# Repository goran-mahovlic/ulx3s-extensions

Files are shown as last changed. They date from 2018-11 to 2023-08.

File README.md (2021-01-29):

# Extension boards for ULX3S



    [x] RFM9X
    [x] OV7670
    [x] GPDI Input/output
    [x] MLX90640
    [x] I2S microphone
    [x] DB9
    [x] SD Card
    [x] MAX31855
    [x] ENC28J60
    [o] I2S Audio
    [o] MIDI in/out
    [o] Poteciometers
    [o] VGA
    [ ] Rotary encoder
    [ ] DC Motor with encoder
    [ ] LCD - DS90CF363B    
    [ ] CH376
    [ ] CAN bus
    [ ] LVDS
    [x] SX1257 - Already in development
    [x] RaspiCam - https://github.com/daveshah1/pmods
 
LoRa front

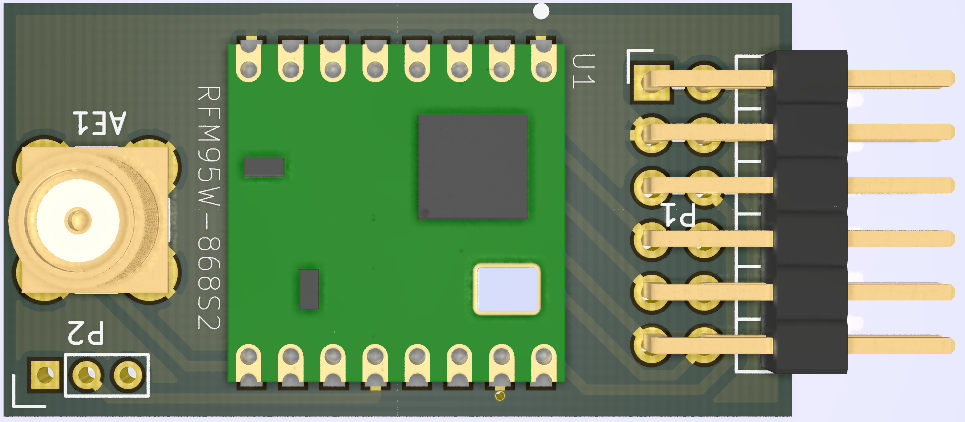
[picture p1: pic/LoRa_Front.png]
LoRa


LoRa back

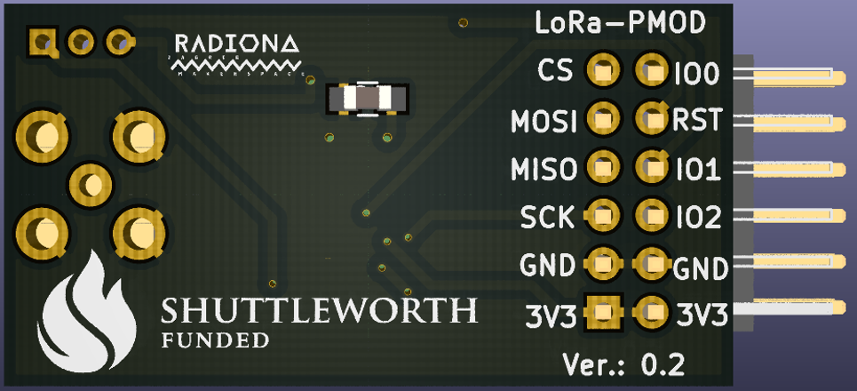
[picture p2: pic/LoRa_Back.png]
LoRa


LoRa rotate

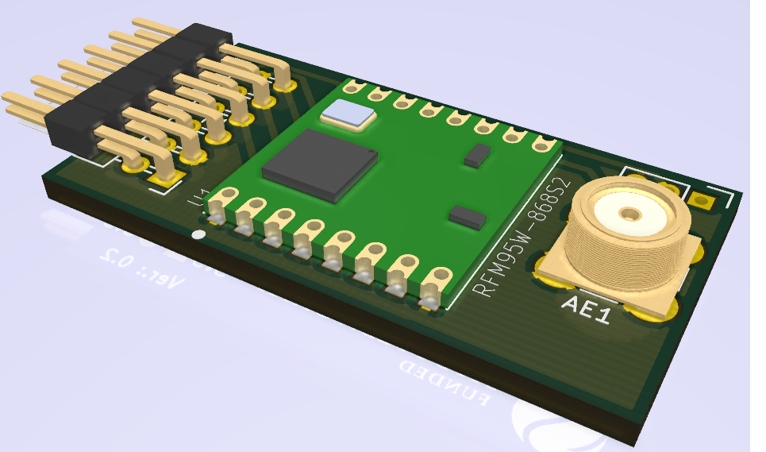
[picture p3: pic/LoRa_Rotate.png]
LoRa


MicroUSB front

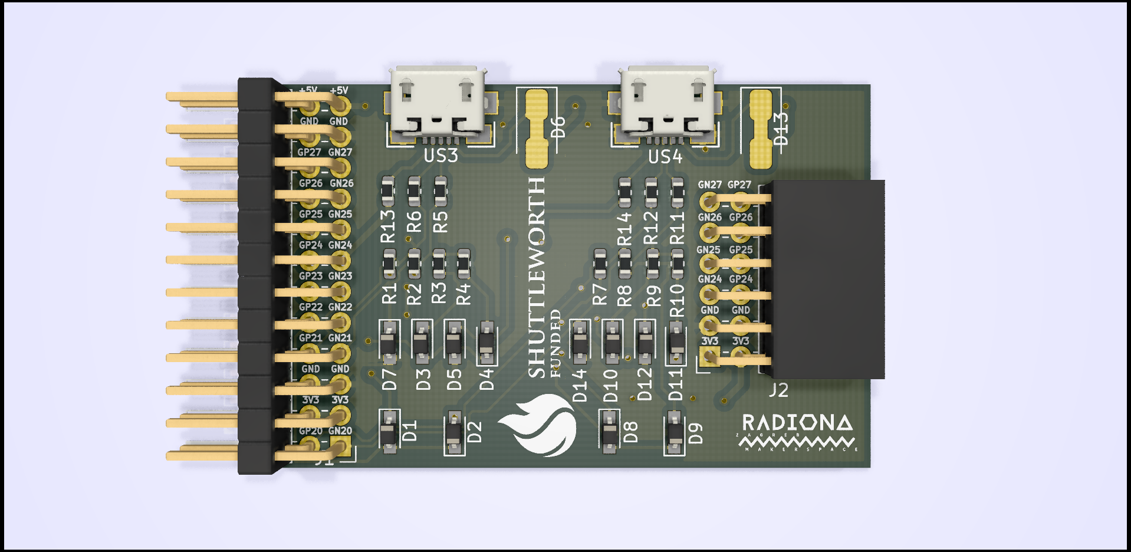
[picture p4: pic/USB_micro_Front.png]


MicroUSB back

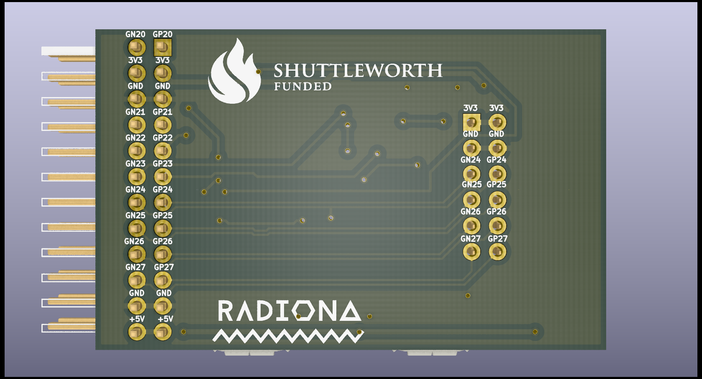
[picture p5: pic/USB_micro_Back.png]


MicroUSB rotate

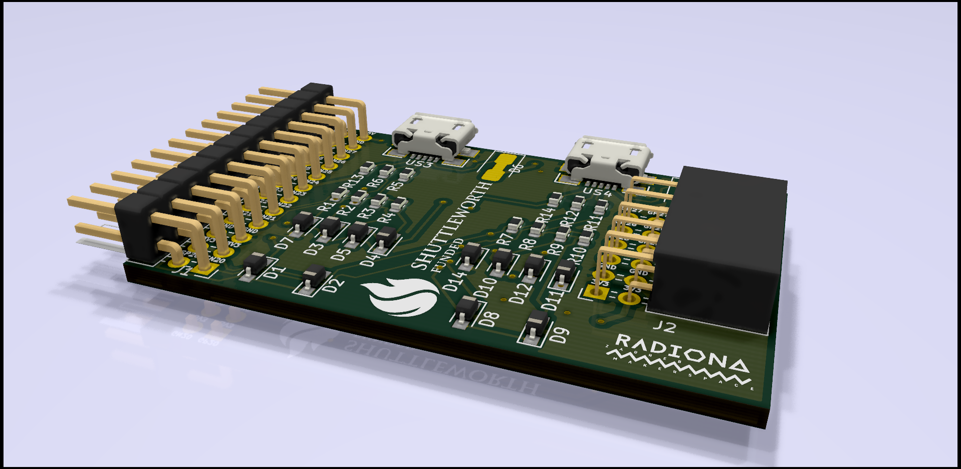
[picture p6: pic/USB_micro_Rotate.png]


USB front

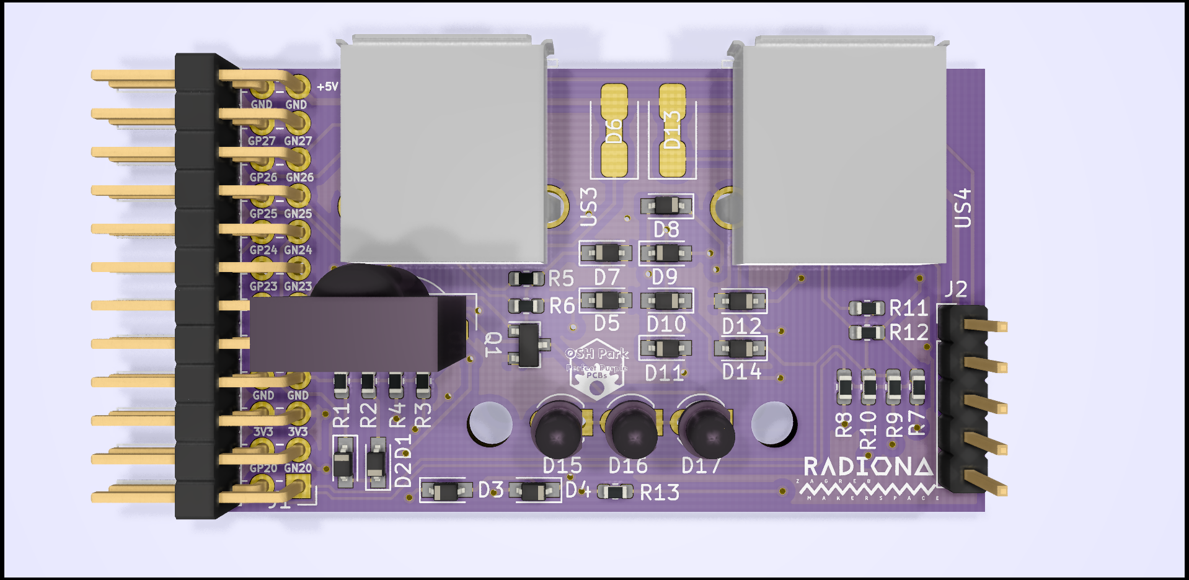
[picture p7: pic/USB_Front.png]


USB back

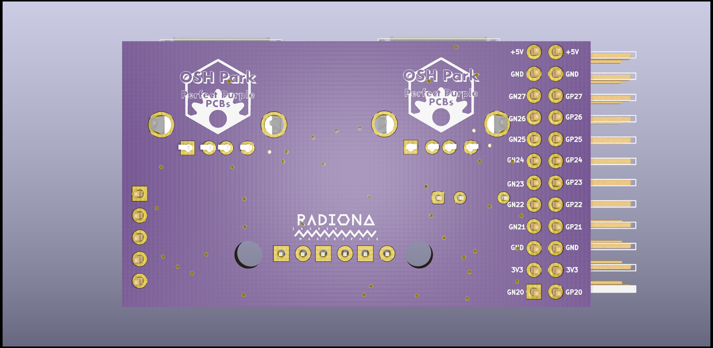
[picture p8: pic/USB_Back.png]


USB rotate

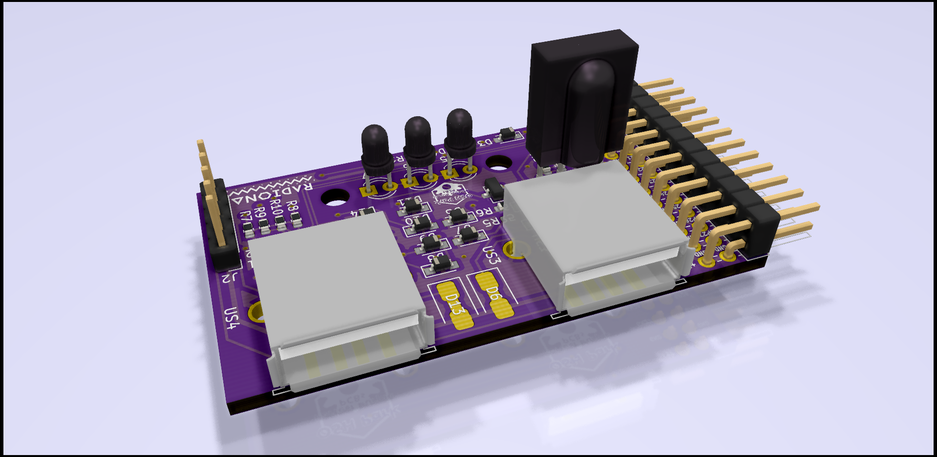
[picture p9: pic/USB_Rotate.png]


ENC28J60 front

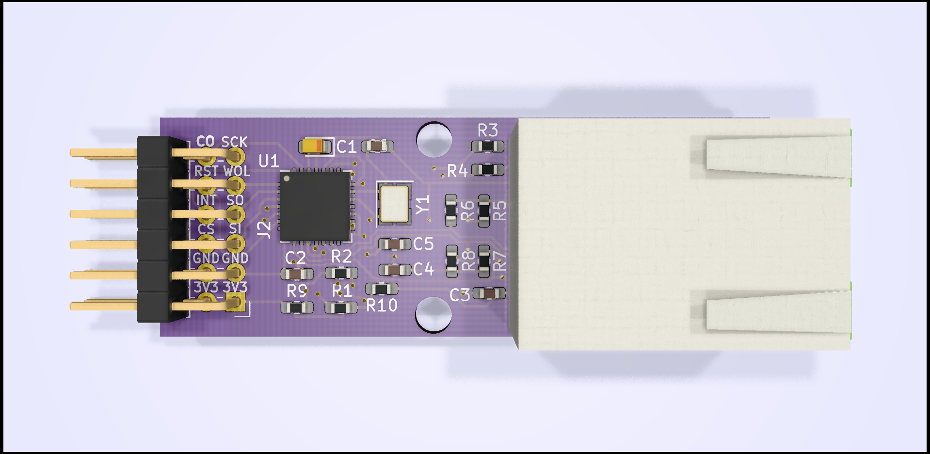
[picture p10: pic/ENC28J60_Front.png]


ENC28J60 rotate

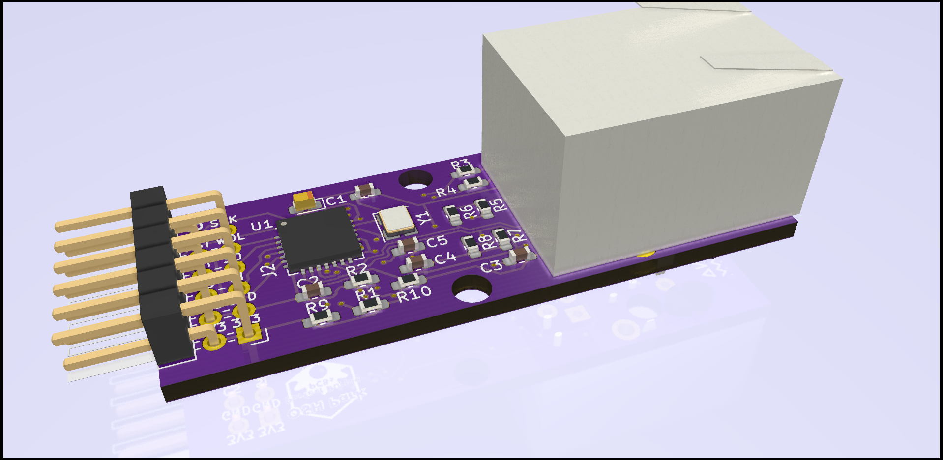
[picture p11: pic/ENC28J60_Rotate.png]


GPDI front

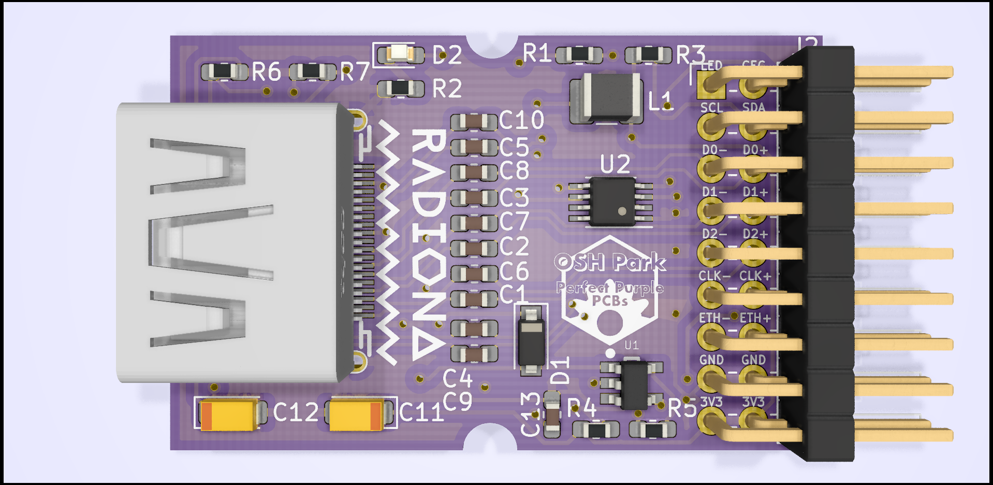
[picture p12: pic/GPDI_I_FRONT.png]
GPDI


GPDI back

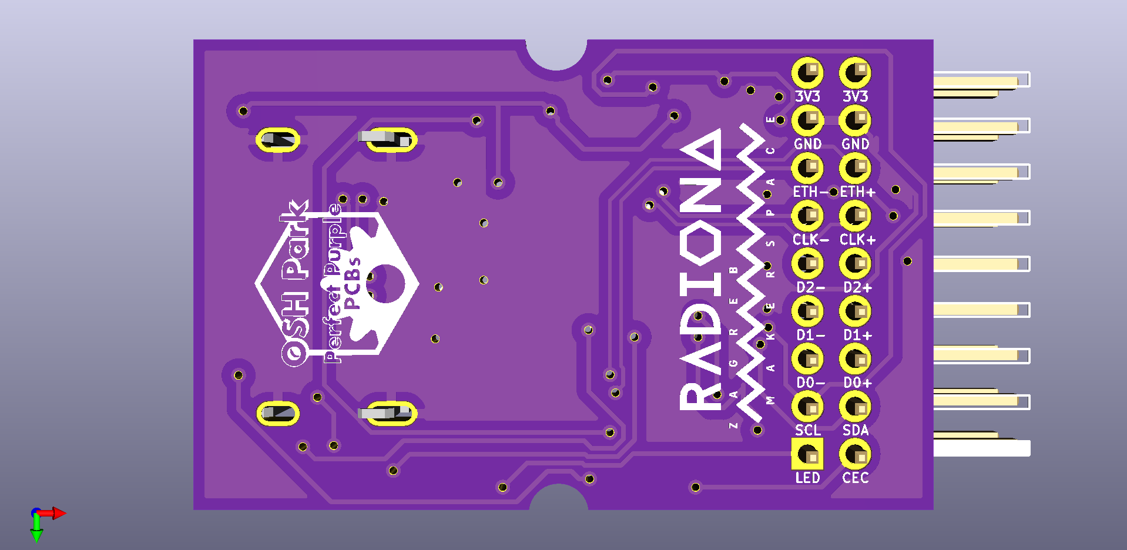
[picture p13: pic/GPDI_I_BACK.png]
GPDI


GPDI rotate

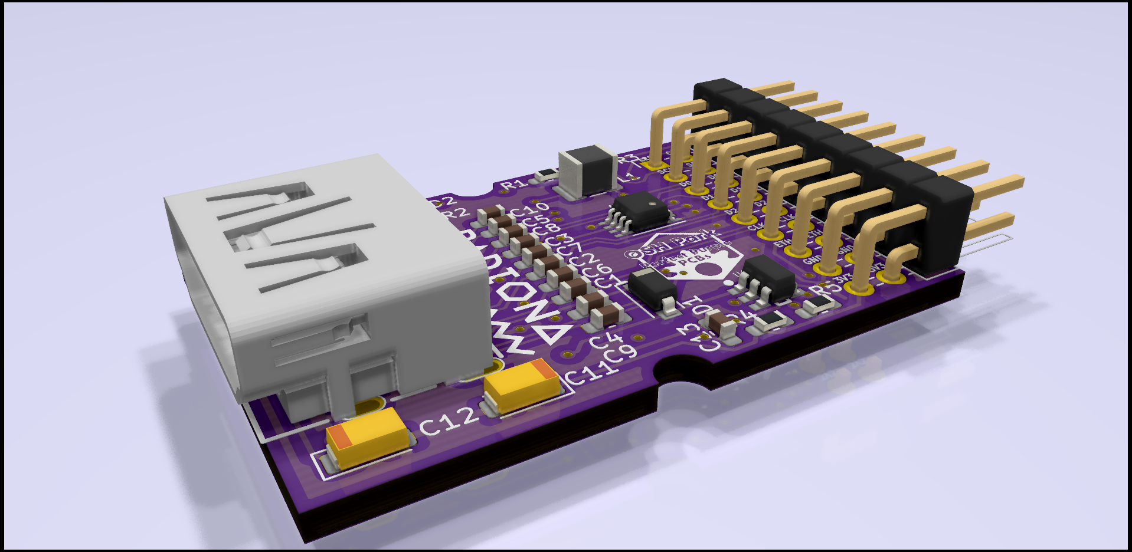
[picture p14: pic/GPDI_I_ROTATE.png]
GPDI


Potenciometar front

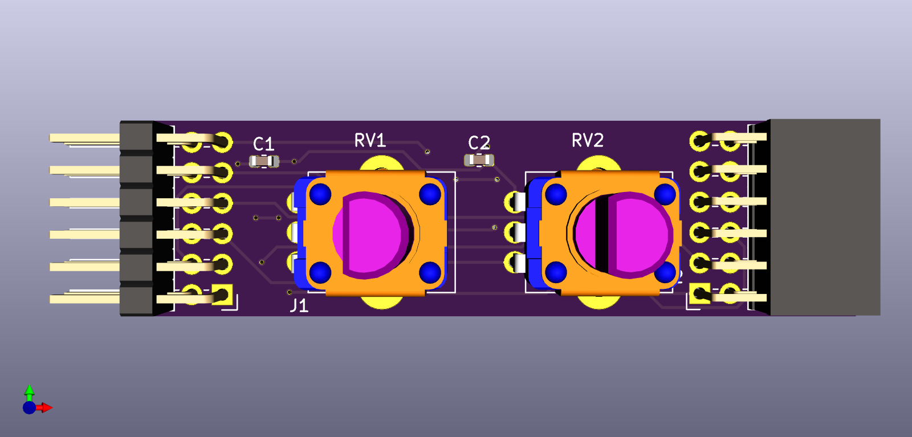
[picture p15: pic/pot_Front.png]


Potenciometar back

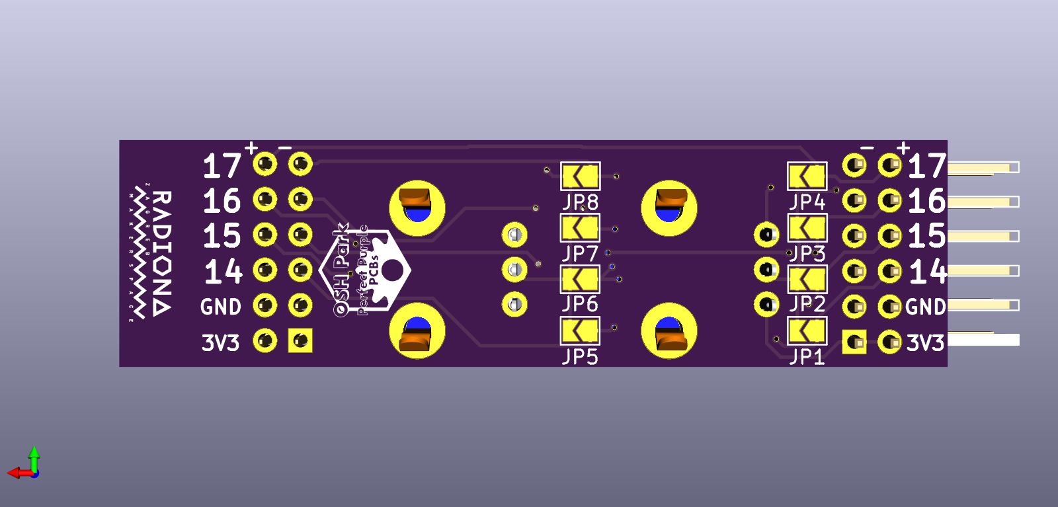
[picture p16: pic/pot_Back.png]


Potenciometar rotate

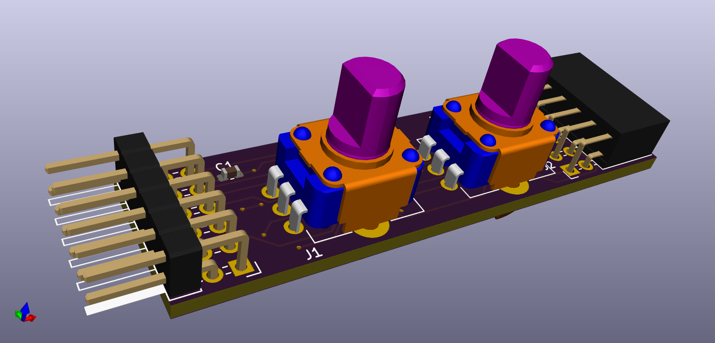
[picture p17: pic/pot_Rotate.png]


MIDI rotate

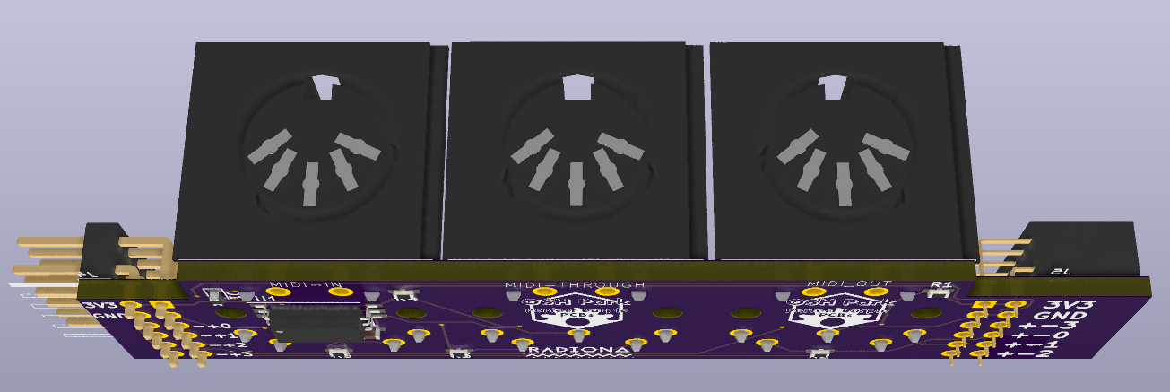
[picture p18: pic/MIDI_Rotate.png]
MIDI


VGA front

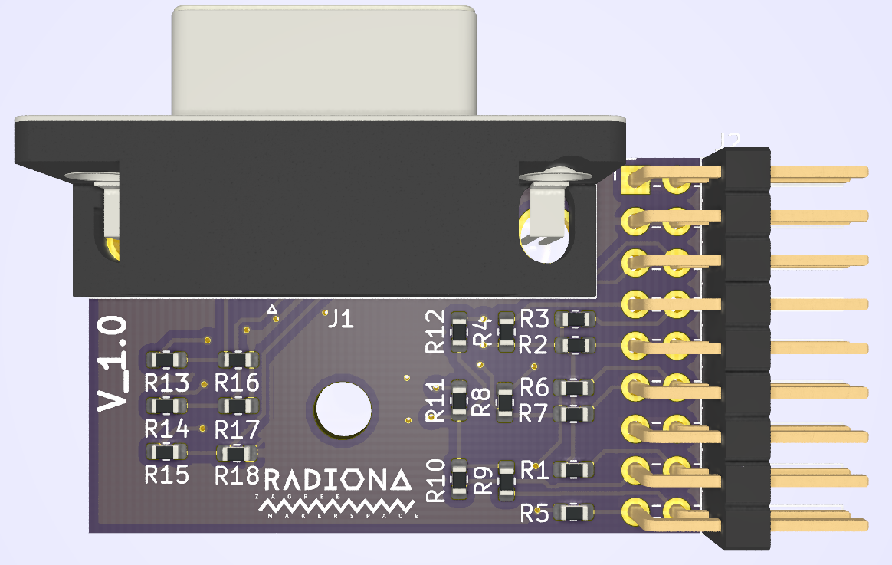
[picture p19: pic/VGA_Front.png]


VGA back

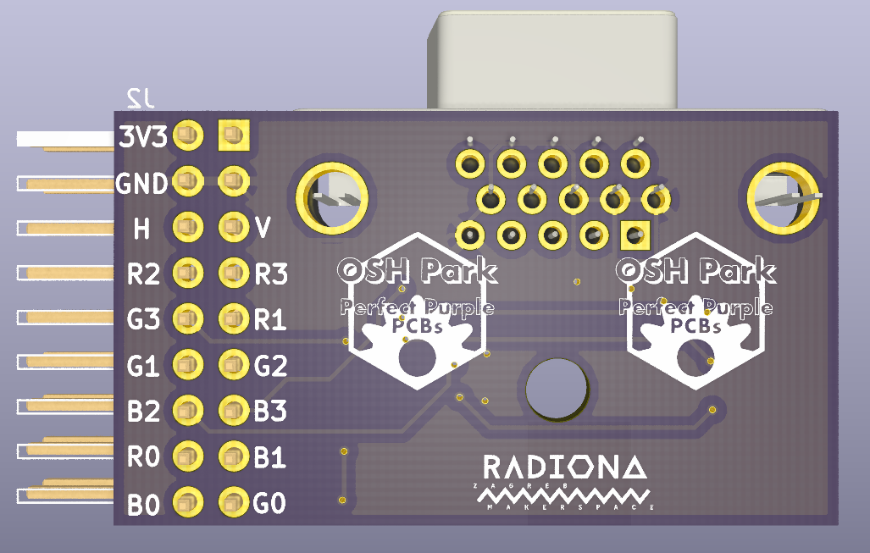
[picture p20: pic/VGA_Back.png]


OV7670 front

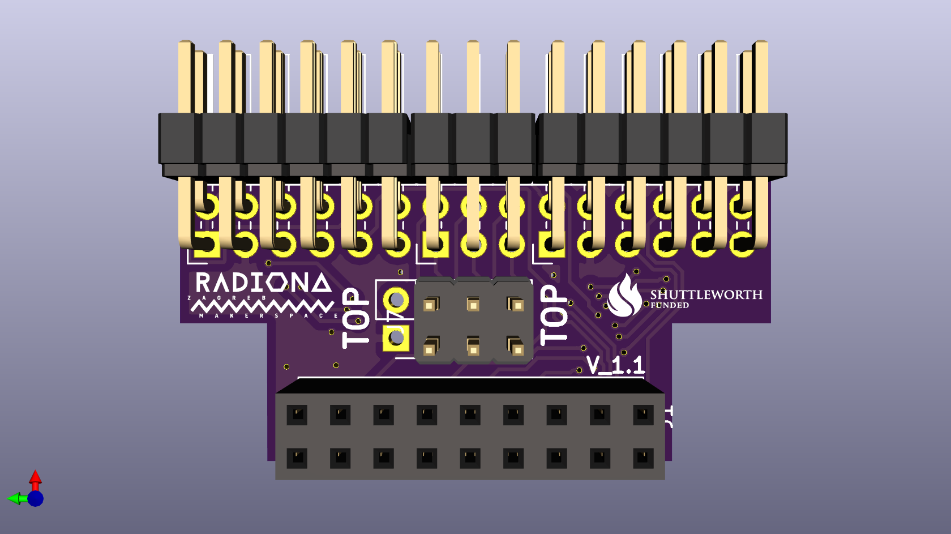
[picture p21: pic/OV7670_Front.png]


OV7670 back

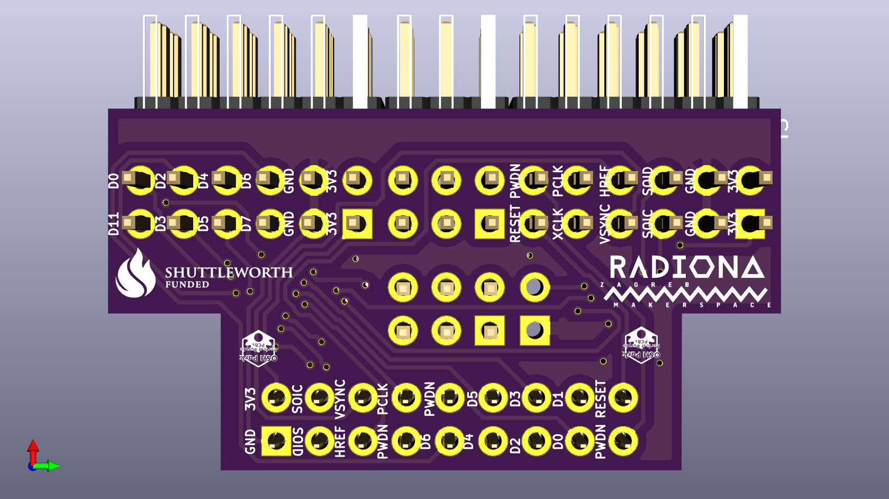
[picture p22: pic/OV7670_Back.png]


OV7670 rotate

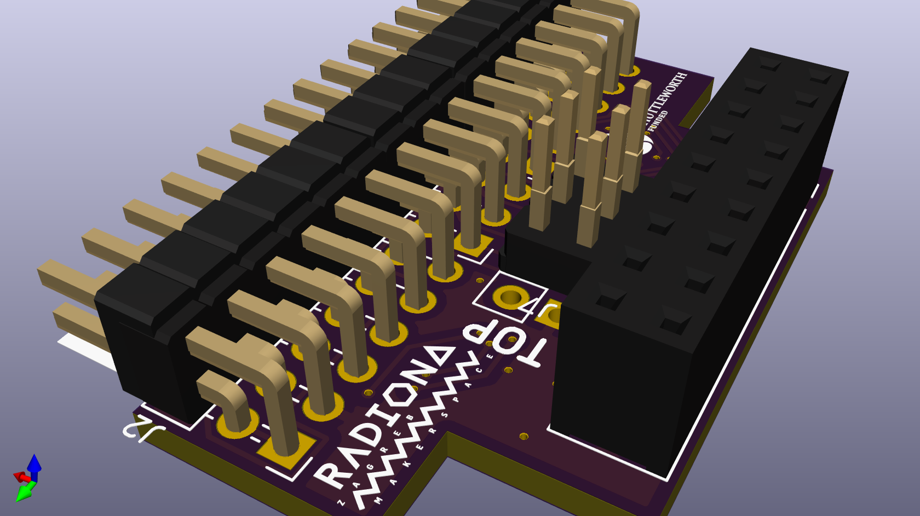
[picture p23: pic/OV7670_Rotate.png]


MLX90640 front

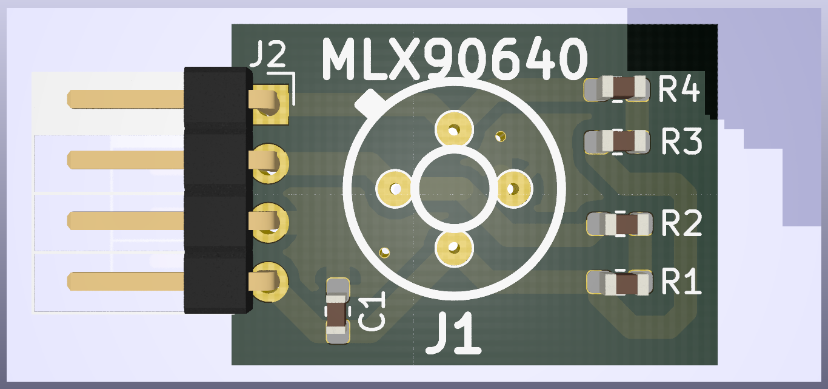
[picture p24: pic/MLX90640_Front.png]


MLX90640 back

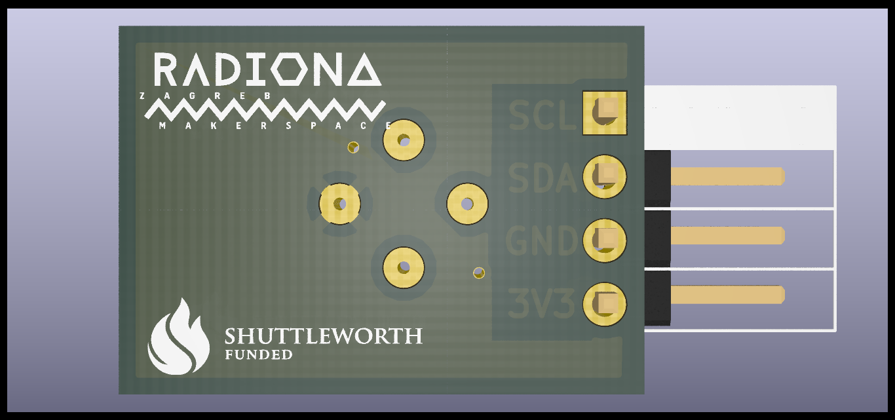
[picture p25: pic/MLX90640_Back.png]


I2SMIC front

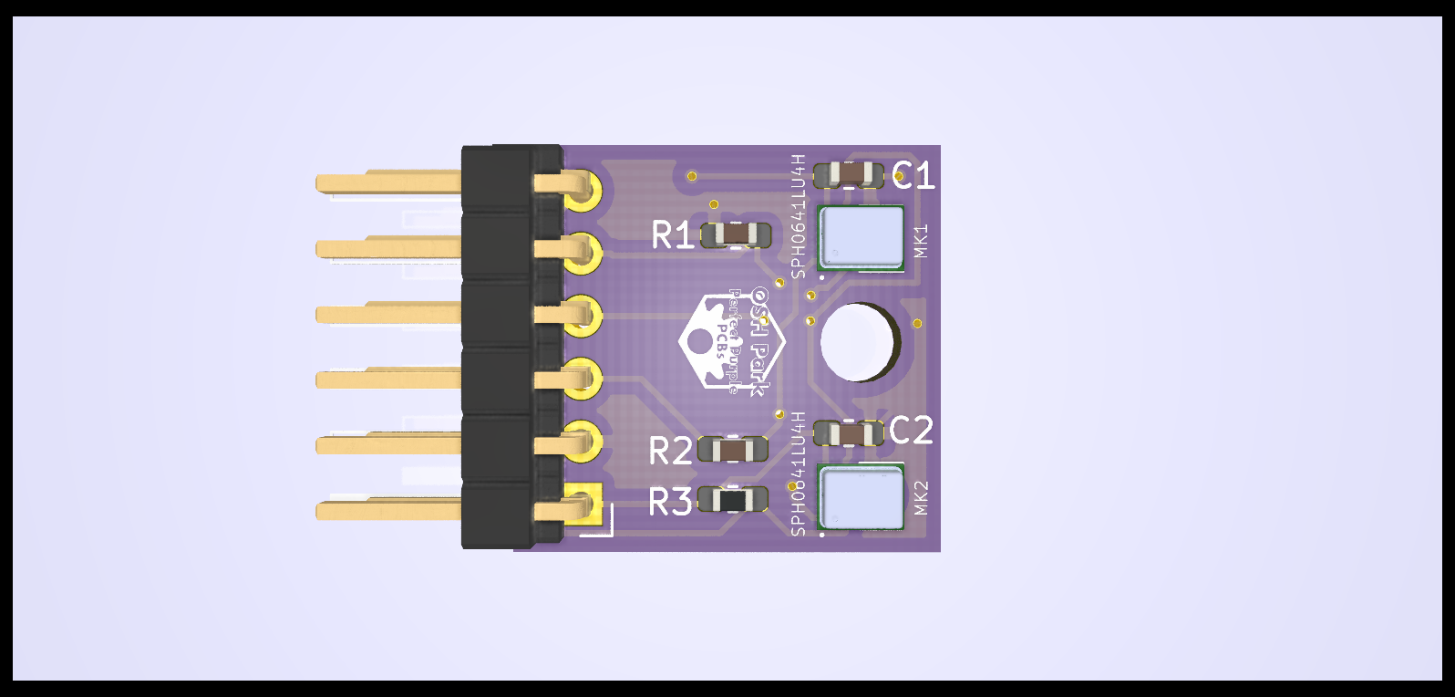
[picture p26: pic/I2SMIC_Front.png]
I2SMIC


I2SMIC back

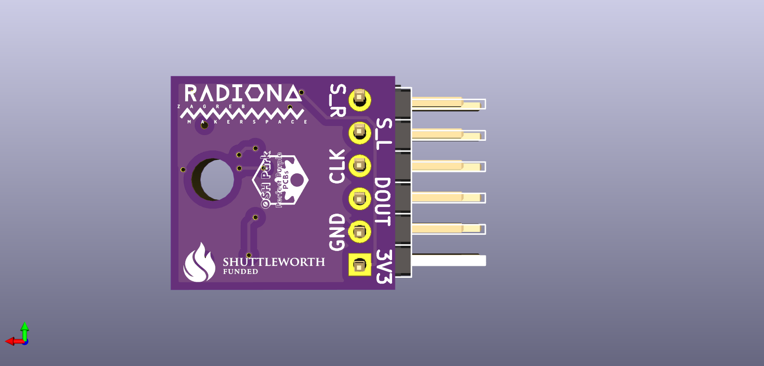
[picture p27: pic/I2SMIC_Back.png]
I2SMIC


I2SMIC rotate

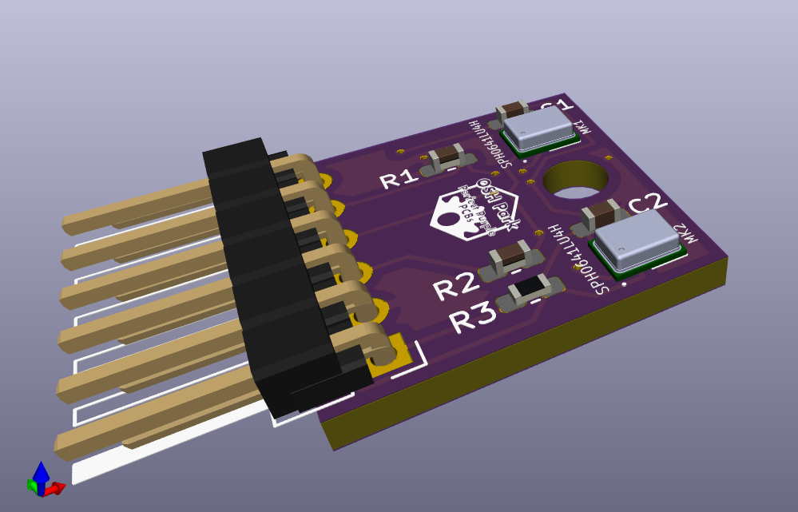
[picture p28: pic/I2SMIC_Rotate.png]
I2SMIC


SD front

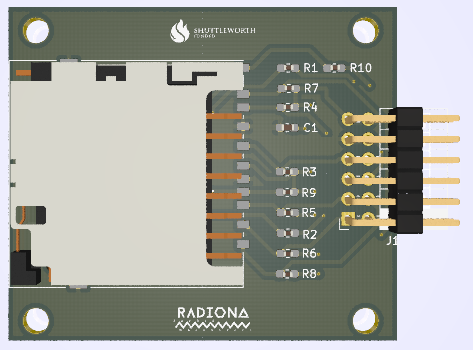
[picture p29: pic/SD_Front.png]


SD back

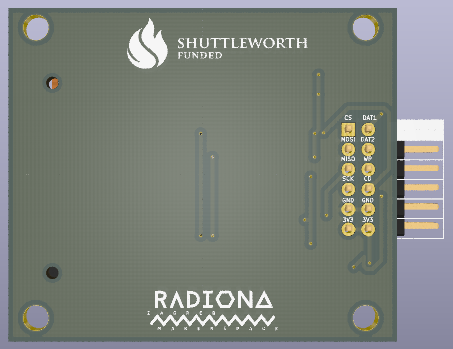
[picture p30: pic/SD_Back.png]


PB9 back

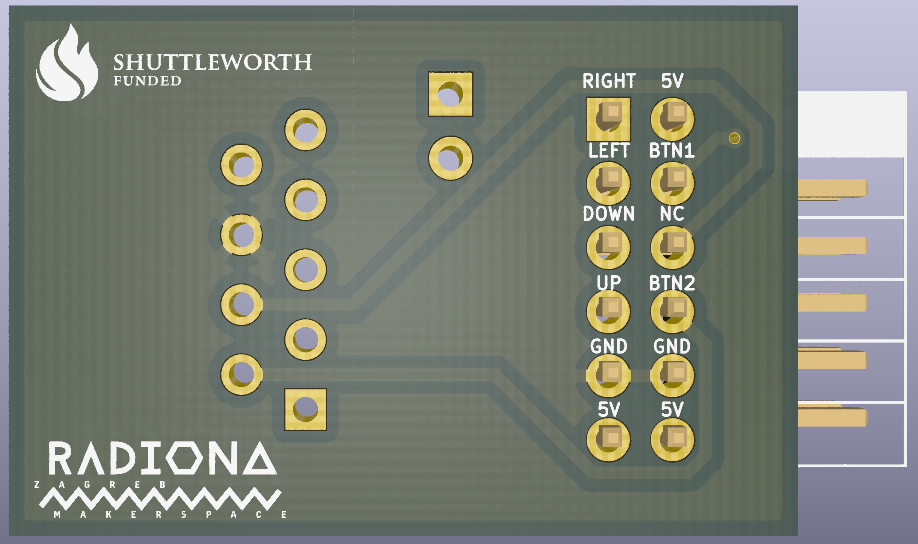
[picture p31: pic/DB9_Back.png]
DB9


MAX31855 front

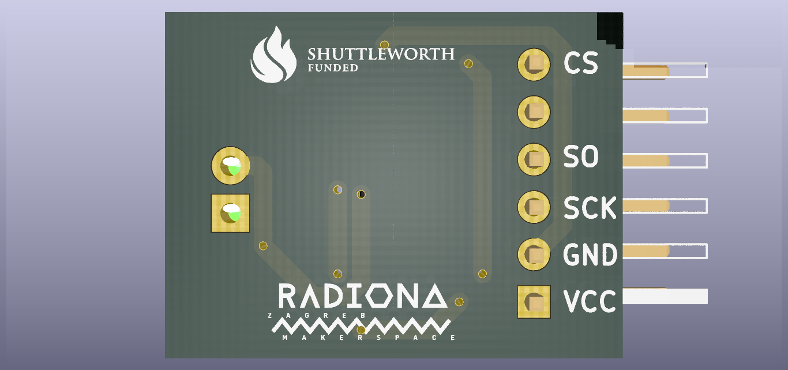
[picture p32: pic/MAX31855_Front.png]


MAX31855 back

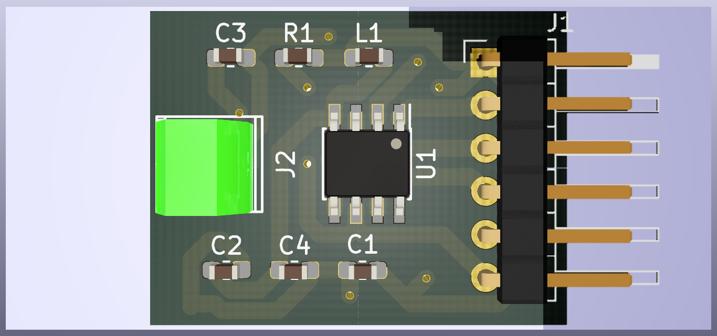
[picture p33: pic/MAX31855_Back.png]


MAX31855 rotate

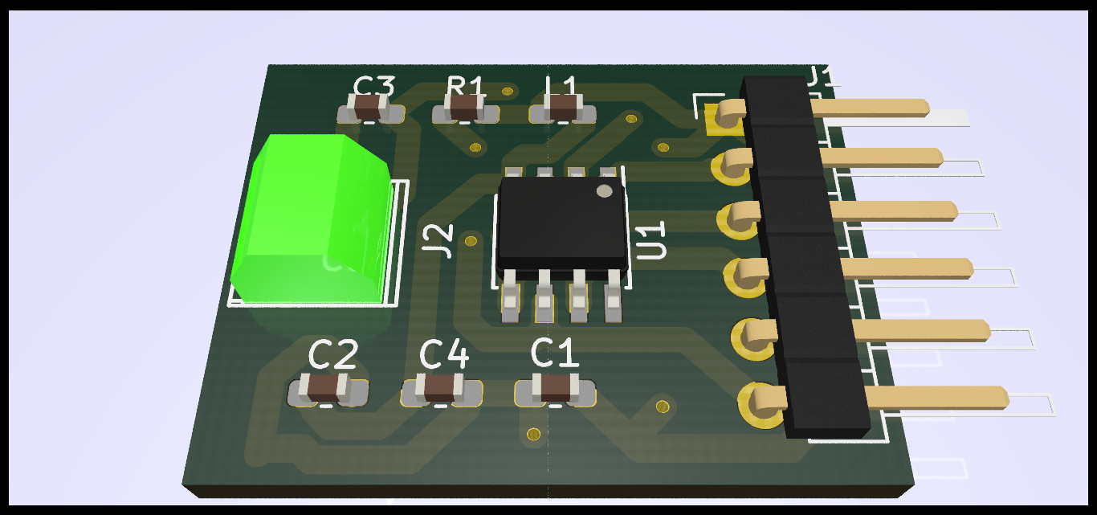
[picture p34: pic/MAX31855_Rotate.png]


Founded by ShuttleworthFoudation

 

Helping hands: Marvin(Radiona), Emard(Radiona), Prizma(Radiona), mmicko, Drew Fustini (OSH Park), SnapEDA, smunaut(tnt)

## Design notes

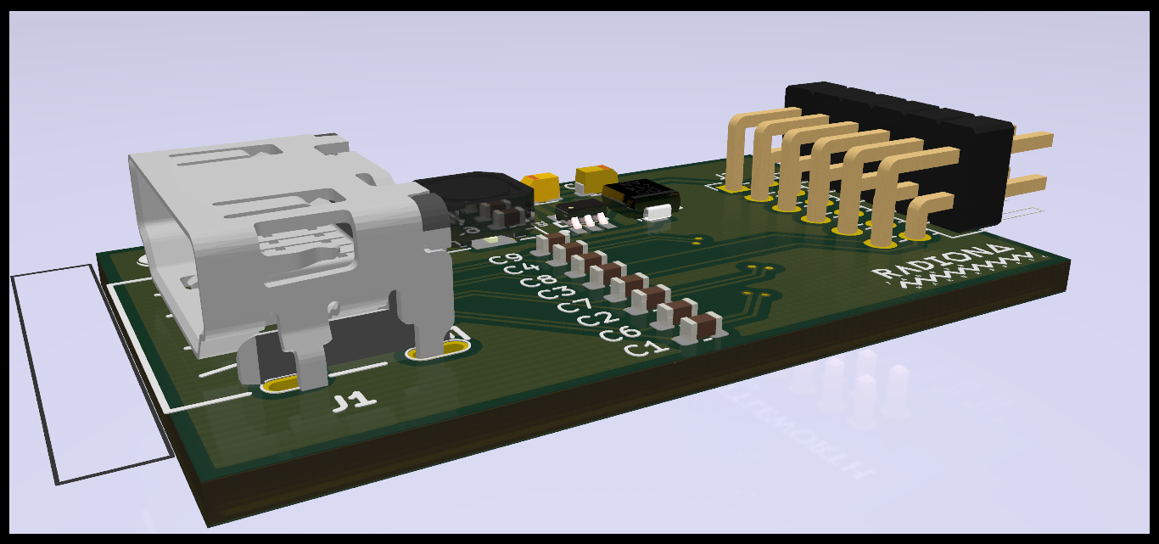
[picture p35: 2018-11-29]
pic/GPDI_Rotate.png

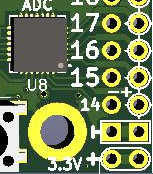
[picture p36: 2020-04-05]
pic/pot.png

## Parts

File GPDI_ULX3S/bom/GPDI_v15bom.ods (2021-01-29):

 |  |  | GPDI V_1.5 BOM list
 | Sourced | Placed | References | Value | Footprint | Quantity
1 |  |  | C11, C12 | 47uF | CP_EIA-3216-10_Kemet-I | 2
2 | ✓ |  | C1, C2, C3, C4, C5, C6, C7, C8, C9 | 220nF | C_0402_1005Metric | 9
3 | ✓ |  | C13 | 470pF | C_0402_1005Metric | 1
4 | ✓ |  | R8, R11, R12, R15, R16, R19, R20, R23 | 50R | R_0402_1005Metric | 8
5 | ✓ |  | R9, R10, R13, R14, R17, R18, R21, R22 | 10K | R_0402_1005Metric | 8
6 | ✓ |  | R2, R6, R7, R29 | 4.7k | R_0402_1005Metric | 4
7 |  |  | R1, R28 | 510 | R_0402_1005Metric | 2
8 | ✓ |  | R3, R4 | 3.3k | R_0402_1005Metric | 2
9 | ✓ |  | R5 | 100k | R_0402_1005Metric | 1
10 |  |  | L1 | 100u | L_1210_3225Metric | 1
11 | ✓ |  | D1 | MBR0520 | D_SOD-123 | 1
12 | ✓ |  | D3 | BZT52C3V6S-7-F | D_SOD-323 | 1
13 | ✓ |  | D2 | LED | LED_0603_1608Metric_Pad1.05x0.95mm_HandSolder | 1
14 | ✓ |  | U1 | RN5RK501A | SOT-23-5 | 1
15 |  |  | U2 | PCA9306 | VSSOP-8_2.3x2mm_P0.5mm | 1
16 | ✓ |  | GPDI | GPDI | CONN-10029449-111RLF | 1
18 |  |  | J2 | CONN | PinHeader_2x09_P2.54mm_Horizontal | 1

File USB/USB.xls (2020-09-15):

Ref | Qnty | Value | Cmp name | Footprint | Description | Vendor
D2, D4, D1, D3, D9, D11, D8, D10, | 8 | 1N914 | D | Diode_SMD:D_SOD-323_HandSoldering | Diode
D5, D7, D12, D14, | 4 | 3.6V | D_Zener_Small_ALT | Diode_SMD:D_SOD-323_HandSoldering | Zener diode, small symbol, filled shape
D6, D13, | 2 | 0 | Jumper_NC_Small | jumper:D_SMA_Jumper_NC | Jumper, normally closed, small symbol
D15, D16, D17, | 3 | LED | LED | LED_THT:LED_D3.0mm_IRBlack | Light emitting diode
J1, | 1 | Conn_02x12_Odd_Even | Conn_02x12_Odd_Even | Connector_PinHeader_2.54mm:PinHeader_2x12_P2.54mm_Horizontal | Generic connector, double row, 02x12, odd/even pin numbering scheme (row 1 odd numbers, row 2 even numbers), script generated (kicad-library-utils/schlib/autogen/connector/)
J2, | 1 | CONN | Conn_01x05 | Connector_PinHeader_2.54mm:PinHeader_1x05_P2.54mm_Vertical | Generic connector, single row, 01x05, script generated (kicad-library-utils/schlib/autogen/connector/)
Q1, | 1 | 2N7002 | 2N7002 | Package_TO_SOT_SMD:SOT-23 | 0.115A Id, 60V Vds, N-channel MOSFET, SOT-23
R1, R3, R7, R9, | 4 | 1.1k | R | Resistor_SMD:R_0603_1608Metric | Resistor
R2, R4, R8, R10, | 4 | 15k | R | Resistor_SMD:R_0603_1608Metric | Resistor
R5, R6, R11, R12, | 4 | 27 | R | Resistor_SMD:R_0603_1608Metric | Resistor
R13, | 1 | 4.7 | R | Resistor_SMD:R_0603_1608Metric | Resistor
U1, | 1 | TSOP17xx | TSOP17xx | OptoDevice:Vishay_CAST-3Pin | Photo Modules for PCM Remote Control Systems
US4, US3, | 2 | USB_A | USB_A | Connector_USB:USB_A_Stewart_SS-52100-001_Horizontal | USB Type A connector

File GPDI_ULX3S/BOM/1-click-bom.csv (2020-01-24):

References | Qty | Description | Manufacturer | MPN | Digikey | Mouser | RS | Newark | Farnell
C11,C12 | 2 |  | AVX | F911A476MAAAJ6 | 478-12528-6-ND | 581F911A476MAAAJ6 |  |  | 2992443RL
C1,C2,C3,C4,C5,C6,C7,C8,C9,C10 | 10 |  | Yageo | CC0603KRX7R8BB224 | 311-1803-6-ND | 603CC603KRX7R8BB224
U1 | 1 |  | Ricoh | RN5RK501A-TR-FE | RN5RK501A-TR-FE-ND | 848RN5RK501ATRFE
U2 | 1 |  | Texas Instruments | PCA9306DCTR | 296-18509-1-ND | 595PCA9306DCTR | 6627415 |  | 3120911
D1 | 1 |  | ON Semiconductor | MBR0520LT1G | MBR0520LT1GOSDKR-ND | 863MBR0520LT1G | 463432 |  | 1783602
P1 | 1 |  | FCI | 10029449-111RLF | 609-4614-1-ND | 64910029449111RLF
D2 | 1 |  | Lite-On | LTST-C170TGKT | 160-1887-6-ND | 859LTSTC170TGKT | 6920922
L1 | 1 |  | Taiyo Yuden | CBC3225T101KRV | 587-6400-1-ND | 963CBC3225T101KRV
C13 | 1 |  | KEMET | C0603C471K3RACTU | 399-9086-1-ND | 80C0603C471K3R |  |  | 2581068
R5 | 1 |  | Panasonic | ERJ-3EKF1003V | P100KHDKR-ND | 667ERJ3EKF1003V | 1755949 |  | 2303232
R3,R4 | 2 |  | Yageo | AC0603FR-073K3L | YAG3605DKR-ND | 603AC0603FR073K3L
R2,R6,R7 | 3 |  | Yageo | AC0603FR-074K7L | YAG3613DKR-ND | 603AC0603FR074K7L
R1 | 1 |  | Yageo | RC0603FR-07510RL | 311-510HRDKR-ND | 603RC0603FR07510RL |  |  | 1799351

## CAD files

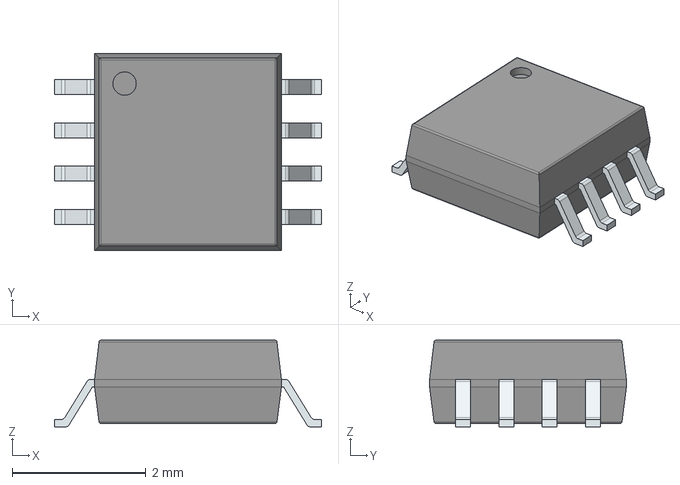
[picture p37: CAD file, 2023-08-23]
parts/PCA9306DCTR/3D/PCA9306DCTR.stp
4.00 x 2.95 x 1.30 mm
PinsArrayLR

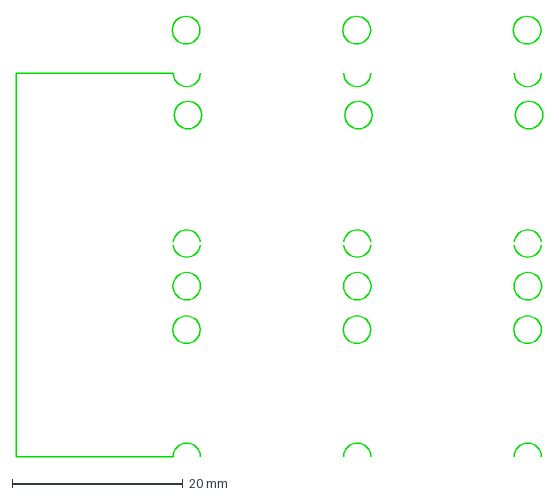
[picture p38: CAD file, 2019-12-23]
parts/pmod_R.dxf
61.8 x 51.7 mm

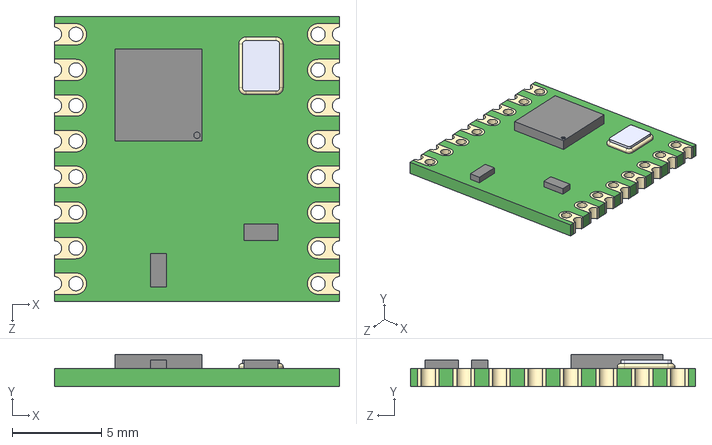
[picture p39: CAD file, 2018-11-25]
parts/RFM95/RFM95W-915S2--3DModel-STEP-56544.STEP
16.0 x 1.80 x 16.0 mm

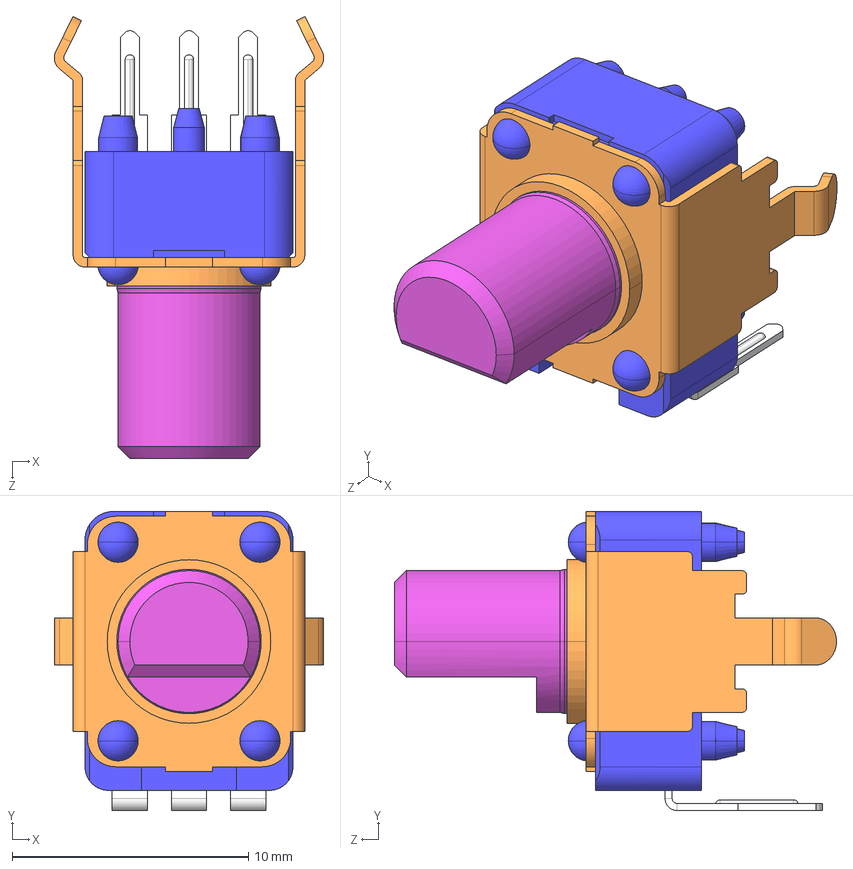
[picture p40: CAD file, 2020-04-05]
parts/RK09K1130/RK09K1130-15.STEP
11.4 x 12.7 x 18.7 mm

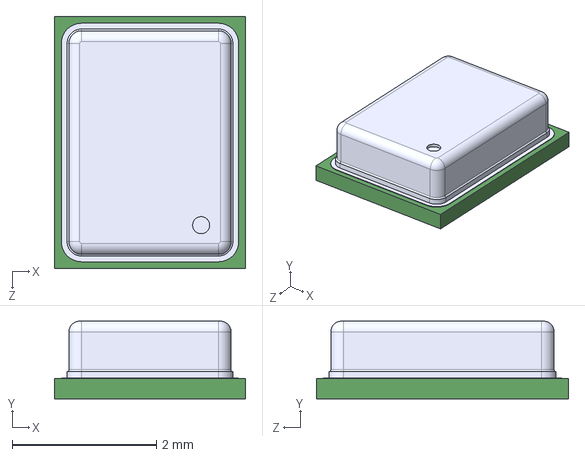
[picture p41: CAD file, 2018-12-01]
parts/SPH0645LM4H/SPH0645LM4H-B--3DModel-STEP-56544.STEP
2.65 x 1.08 x 3.50 mm

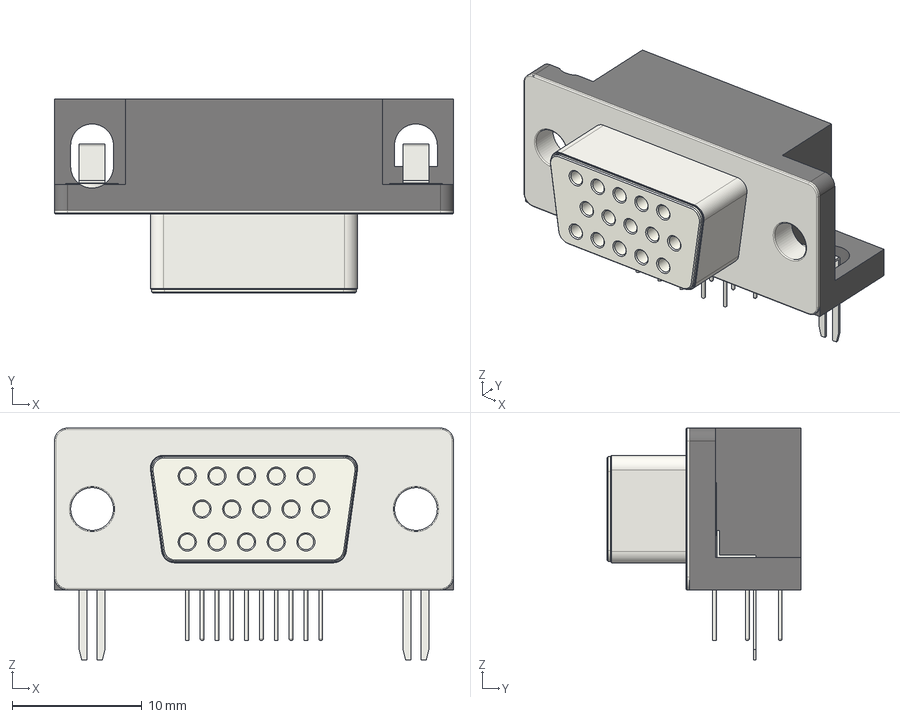
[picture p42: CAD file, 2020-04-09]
parts/VGA/3D/DSUB-15-HD_Female_Horizontal_P2.29x1.98mm_EdgePinOffset3.03mm_Housed_MountingHolesOffset4.94mm.step
30.8 x 15.0 x 17.9 mm

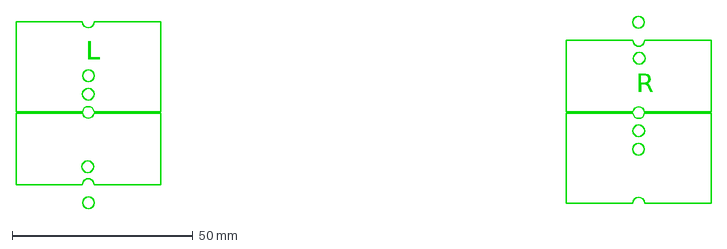
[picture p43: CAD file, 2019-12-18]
parts/pmods.dxf
L
R

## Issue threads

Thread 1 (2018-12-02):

HDMI - inductor is to large

goran-mahovlic, 2018-12-02:
it should give few mA - current inductor is to large

goran-mahovlic, 2019-12-14:
Changed complete board to enable INPUT

Closed 2019-12-14.

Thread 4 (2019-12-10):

New HDMI input PMOD is needed

goran-mahovlic, 2019-12-10:
GP13 ETH+
GN13 ETH-
GP12 CLK+
GN12 CLK-
GP11 D2+
GN11 D2-
GP10 D1+
GN10 D1-
GP9 D0+
GN9 D0-
GP8 SDA over i2c chip
GN8 SCL over  i2c chip
GP7 CEC over 510 ohm resistor
GN7 onboard LED

goran-mahovlic, 2019-12-14:
Done - needs testing

Closed 2019-12-14.

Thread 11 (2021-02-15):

garmin 8-pin flex PMOD wished

emard, 2021-02-15:
HI

Garmin produces OEM GPS modules that have 8-pin connector
for flex cable with TTL serial data and PPS signal. A PMOD would
be great  that is described as

Garmin OEM 15 L and H Flex Cable Socket 8 Pin
Garmin OEM GPS 15 L and H 1mm Pitch Power Data Cable 8 Pin

"L" means low-voltage version 3.3V and suitable for PMOD.
H is same connector but high voltage, should not be considered
supporting here.

Some other products internally also seem to have same
connector, though undocumented so we are not yet sure wil
it work. Here is picture of open Garmin GLO which has
probably the same connector.

https://fccid.io/IPH-01156/Internal-Photos/Internal-Photos-1742266.pdf

Pinout is described here on page 9

https://static.garmin.com/pumac/237_TechnicalSpecifications.pdf

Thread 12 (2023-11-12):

The PS2/PS2.kicad_pcb file is blank

dgraham-io, 2023-11-12:
I was hoping to build a PS2 adapter, but it seems that the file kicad file contains an empty board.?

dgraham-io, 2023-11-12:
Sorry, I just realized I may have misunderstood a projects comments ( https://github.com/lawrie/ulx3s_mac128 ) about how they are connecting PS/2 devices.  I'm guessing they are using the USB board, which I have already purchased.

Closed 2023-11-12.

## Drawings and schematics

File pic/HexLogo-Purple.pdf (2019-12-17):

## OSH Park OSH Park

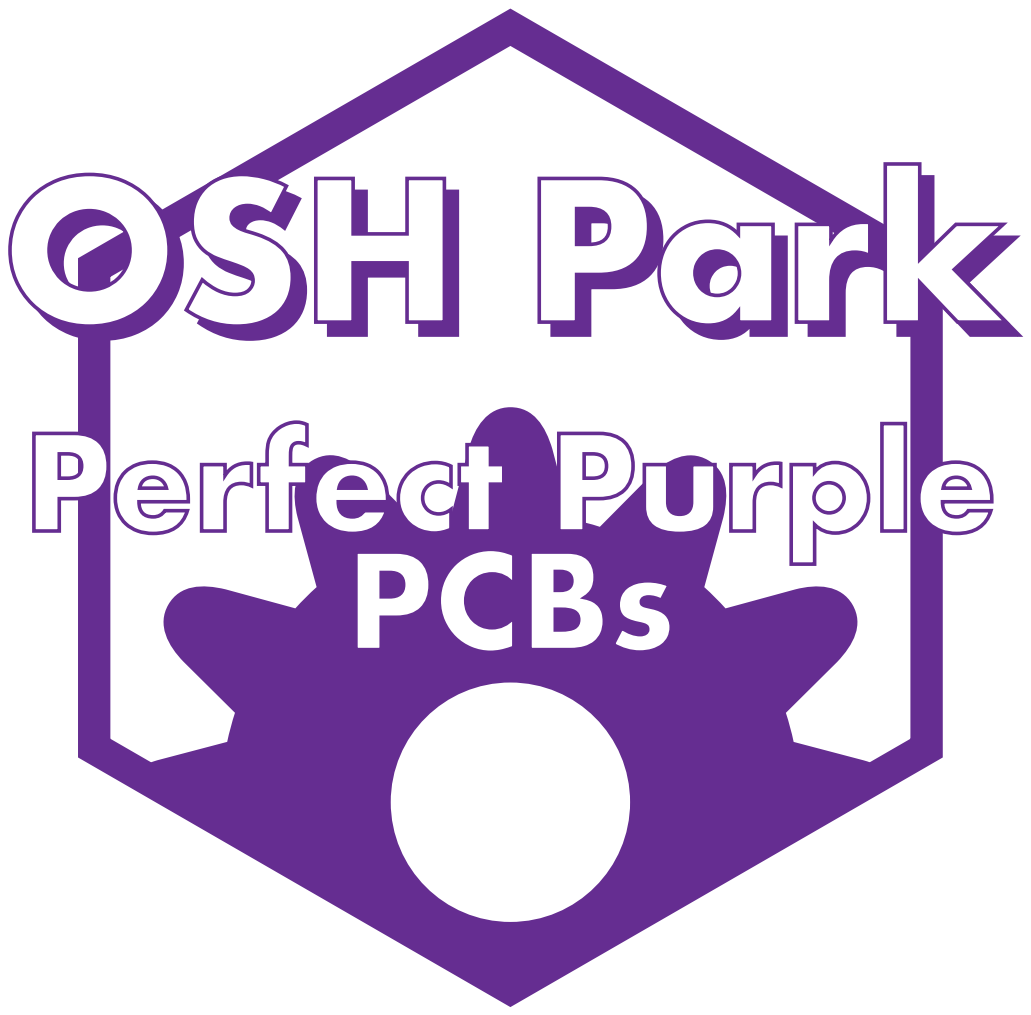
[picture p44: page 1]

Perfect Purple PCBs

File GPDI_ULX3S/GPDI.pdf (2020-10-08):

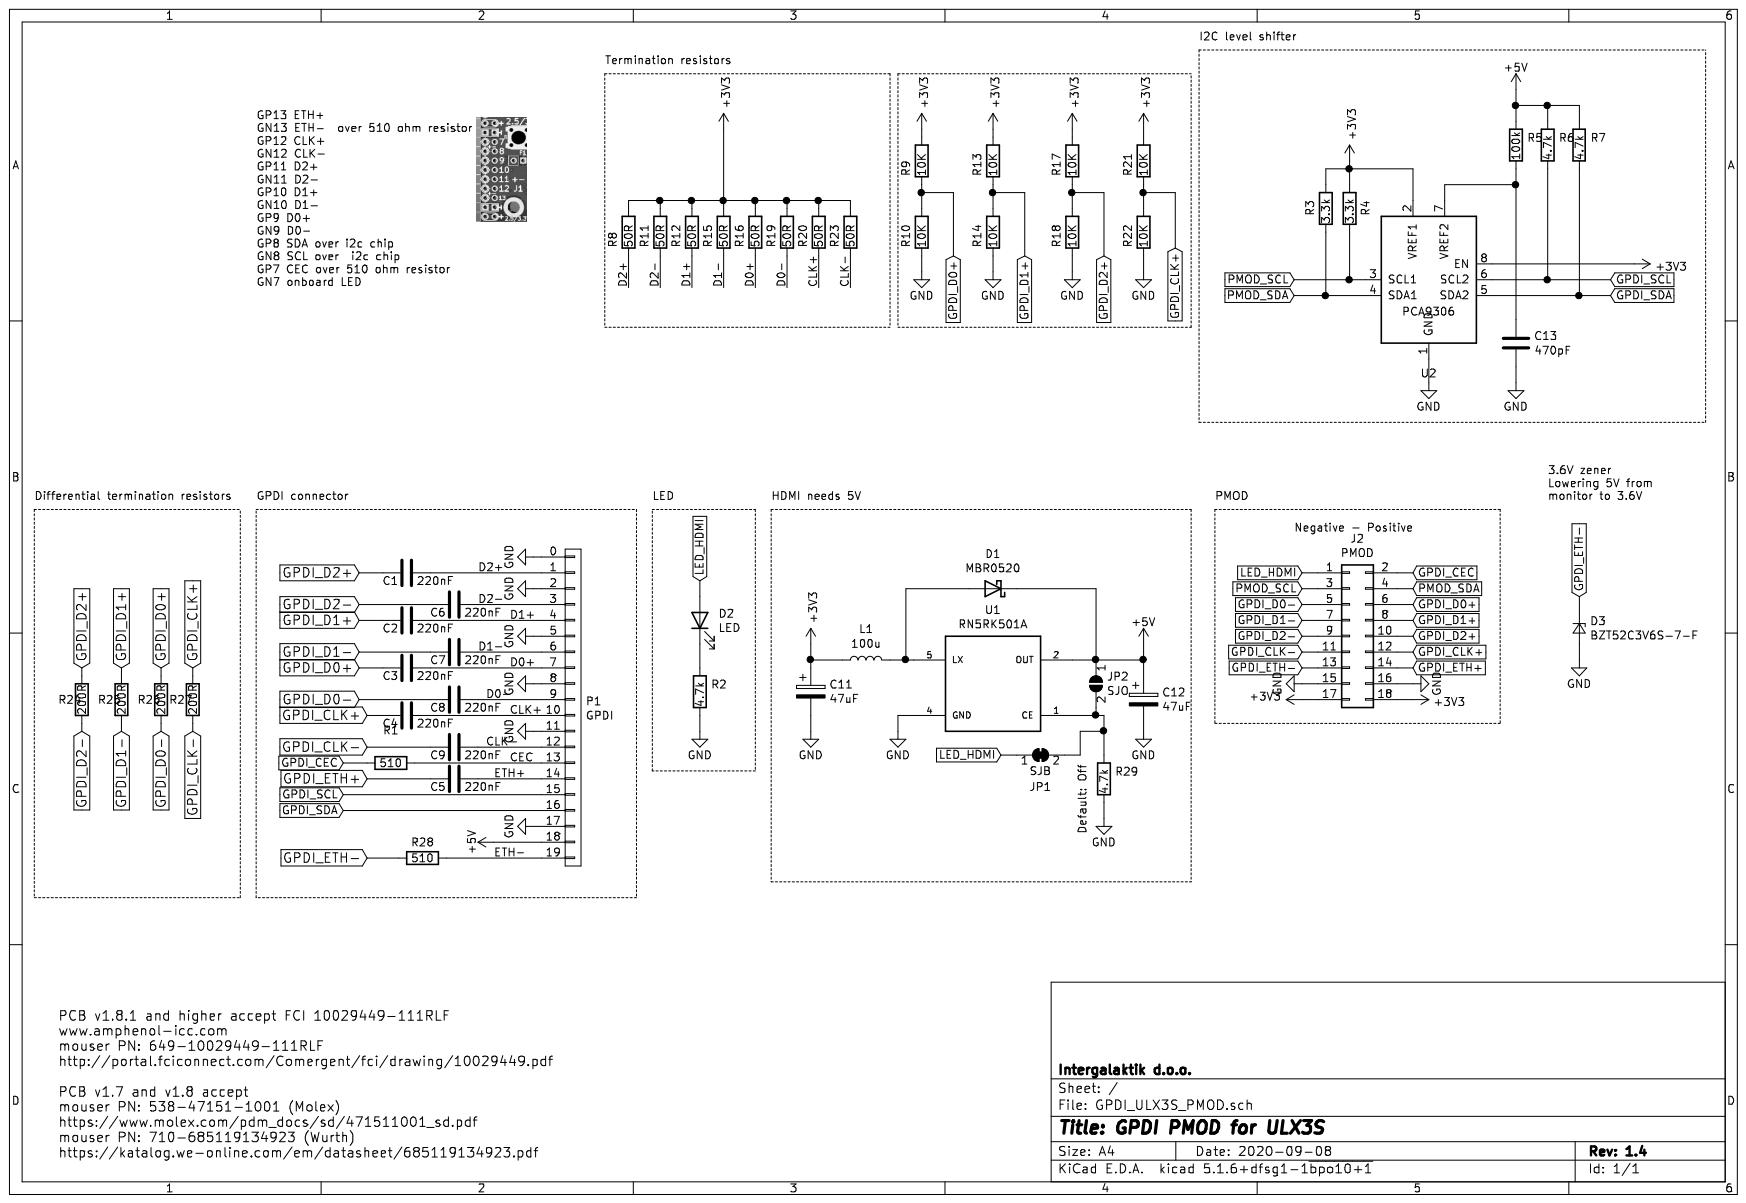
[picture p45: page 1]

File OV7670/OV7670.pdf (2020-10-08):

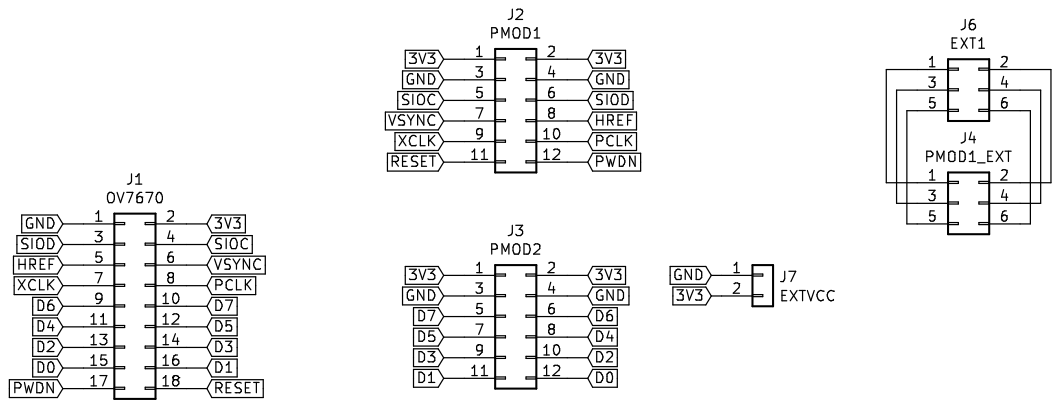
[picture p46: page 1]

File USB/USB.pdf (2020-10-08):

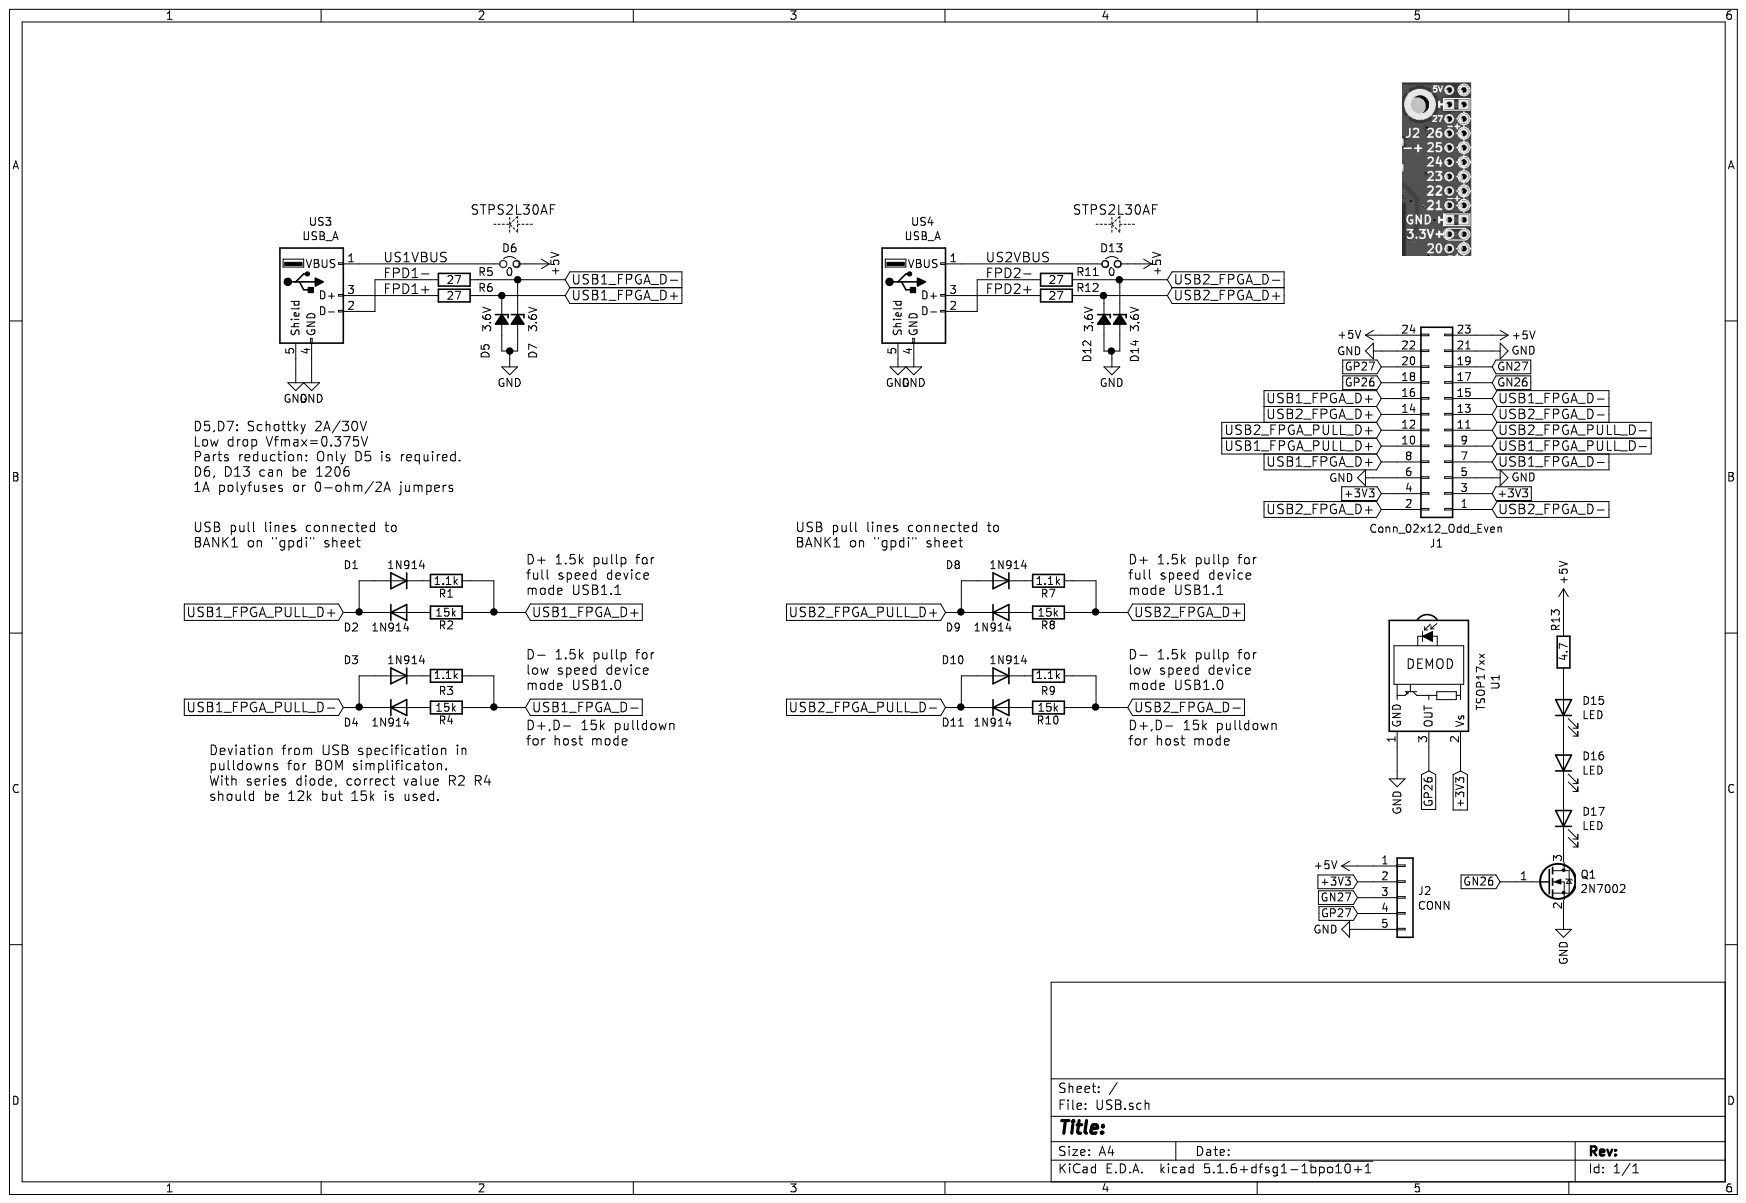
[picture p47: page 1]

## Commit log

2018-11-25 Adding initial version of LoRa PMOD for FPGA
    [LoRa_PMOD.kicad_pcb, LoRa_PMOD.sch, RFM95W-915S2--3DModel-STEP-56544.STEP]
2018-11-25 Adding netlist, and associate
    [LoRa_PMOD.sch]
2018-11-25 Fixing 3D model
    [LoRa_PMOD.sch]
2018-11-25 fixing 3D model dimension
    [LoRa_PMOD.kicad_pcb]
2018-11-25 Fixing PMOD pinout
    [LoRa_PMOD.kicad_pcb, LoRa_PMOD.sch]
2018-11-25 Fixing PMOD, adding text to back
    [LoRa_PMOD.kicad_pcb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]
2018-11-25 New version
    [LoRa_PMOD.kicad_pcb, LoRa_PMOD.sch, _saved_LoRa_PMOD.sch]
2018-11-25 Adding ground plane
    [LoRa_PMOD.kicad_pcb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]
2018-11-25 Moving text
    [LoRa_PMOD-B.Cu.gbr, LoRa_PMOD-B.SilkS.gbr, LoRa_PMOD-F.Cu.gbr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]
2018-11-25 Adding new pics
    [LoRa_PMOD.kicad_pcb]
2018-11-25 Changing sch
    [LoRa_PMOD.sch, _saved_LoRa_PMOD.sch]
2018-11-26 Adding Emard suggestions
    [LoRa_PMOD.kicad_pcb]
2018-11-26 switching to kicad v5 - edcuts not working
    [LoRa_PMOD-2018-11-26-17-35-28.sch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]
2018-11-26 Edge cuts
    [LoRa_PMOD-B.Cu.gbl, LoRa_PMOD-B.Mask.gbs, LoRa_PMOD-B.SilkS.gbo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]
2018-11-26 Adding new render pictures
    [LoRa_PMOD-B.Cu.gbr, LoRa_PMOD-B.Mask.gbr, LoRa_PMOD-B.SilkS.gbr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]
2018-11-26 Adding new images
    [LoRa_PMOD.kicad_pcb]
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2018-11-26 Adding OV7670 - PMOD shematics
    [arduCam_RC522.kicad_pcb, arduCam_RC522.sch]
2018-11-27 Adding pcb for camera
    [arduCam_RC522.kicad_pcb, arduCam_RC522.sch]
2018-11-28 Update PCB
    [arduCam_RC522.kicad_pcb]
2018-11-28 Adding in labels
    [arduCam_RC522.kicad_pcb]
2018-11-28 Routing OV7670 - files cleanup
    [OV7670.kicad_pcb, OV7670.sch, RFM95W-915S2--3DModel-STEP-56544.STEP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]
2018-11-28 Adding GND and VCC to EXT connector
    [OV7670.kicad_pcb, OV7670.sch]
2018-11-28 Adding NCP as a part
    [HDMI.kicad_pcb, HDMI.sch]
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2018-11-29 Adding MLX90640
    [MLX90640.kicad_pcb, MLX90640.sch]
2018-12-01 Adding I2S audio
    [I2C_MIC.kicad_pcb, I2C_MIC.sch, SPH0645LM4H-B--3DModel-STEP-56544.STEP]
2018-12-02 Fixing I2C_MIC folder
    [I2C_MIC.kicad_pcb, I2C_MIC.sch]
2018-12-02 Adding SD card
    [SD.kicad_pcb, SD.sch, _saved_LoRa_PMOD.sch]
2018-12-02 Fixing pinouts and pictures
    [HDMI.kicad_pcb, LoRa_PMOD.sch, PB9.kicad_pcb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]
2018-12-02 Fixing I2S-MIC
    [HDMI.kicad_pcb, I2C_MIC.kicad_pcb, I2C_MIC.sch]
2018-12-02 Fixing DB9
    [PB9.kicad_pcb]
2018-12-02 Adding PS2 schematics
    [PS2.kicad_pcb, PS2.sch]
2018-12-03 Adding schematics for I2S audio
    [I2S_Audio.kicad_pcb, I2S_Audio.sch]
2018-12-03 Adding MAX31855
    [MAX31855.kicad_pcb, MAX31855.sch]
2018-12-03 Adding initial PCB
    [I2S_Audio.sch]
2018-12-15 New versions
    [HDMI.kicad_pcb, I2C_MIC.kicad_pcb, I2S_Audio.kicad_pcb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]
2019-12-10 Changing schematic tu use bidirectional pins
    [HDMI.sch]
2019-12-11 Changing HDMI connector -- initial placement
    [HDMI.kicad_pcb, HDMI.sch]
2019-12-11 Finished routing HDMI INPUt
    [HDMI.kicad_pcb, HDMI.sch]
2019-12-11 Adding logos
    [HDMI.kicad_pcb]
2019-12-12 Adding initial dual USB shield
    [USB.kicad_pcb, USB.sch]
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2019-12-13 all routed with micro USB connectors
    [USB.sch]
2019-12-13 HDMI update
    [HDMI.kicad_pcb]
2019-12-13 Adding female connector for PMOD
    [USB.kicad_pcb, USB.sch]
2019-12-13 Adding micro USB - will rework USB
    [USB.kicad_pcb, USB.sch]
2019-12-13 Adding USB-A 3D model
    [USB.kicad_pcb, USB.sch]
2019-12-13 Fully routed USB PMOD
    [USB.kicad_pcb]
2019-12-14 Fixing 3D path
    [USB.kicad_pcb]
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2019-12-18 Adding screws - adding OSH Park logos
    [HDMI.kicad_pcb, HDMI.sch]
2019-12-19 Adding new HDMI version with new logos, and holes for screws
    [HDMI.kicad_pcb]
2019-12-21 Adding two missing pins
    [USB.sch]
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2019-12-23 Ripoff USB adding transmit receive
    [USB.kicad_pcb, USB.sch]
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2019-12-23 Adding new routed PCB
    [USB.kicad_pcb, USB.sch]
2019-12-24 Adding missing connections
    [USB.kicad_pcb, USB.sch]
2019-12-24 Adding text not PMOD to board
    [USB.kicad_pcb]
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2019-12-24 Adding ISH park logo
    [OV7670.kicad_pcb]
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2019-12-30 Adding one click BOM
    [1-click-bom.csv]
2020-01-24 Adding pullups for HDMI input
    [HDMI.kicad_pcb, HDMI.sch]
2020-01-25 Changing DC-DC - rerouting
    [HDMI.kicad_pcb, HDMI.sch]
2020-01-28 Rerouting all, placing most components on top layer
    [HDMI.kicad_pcb]
2020-01-28 Adding LCD test shiled
    [DS90CF364.kicad_pcb, DS90CF364.sch]
2020-04-04 Adding jumpers and diff termination to shematics
    [HDMI-B_Cu.gbr, HDMI-B_Mask.gbr, HDMI-B_SilkS.gbr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]
2020-04-04 Just one jumper for termination resistors
    [HDMI.sch]
2020-04-04 Finished PCB routing, adding new zipped gerbers
    [HDMI.kicad_pcb, HDMI.sch]
2020-04-04 Adding new OV7670 with gerber zip
    [OV7670.kicad_pcb, OV7670.sch]
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2020-04-07 Adding shift by one suggested by tnt
    [Poteciometers.kicad_pcb, Poteciometers.sch]
2020-04-08 Adding version number, adding gerber zip
    [midi.kicad_pcb]
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2020-04-09 Connecting VGA connector to GND
    [VGA.kicad_pcb]
2020-09-05 Adding new shematics Fix #5 Fix #7
    [HDMI.sch]
2020-09-05 Fix #10 Fix #9 Fix #8
    [HDMI.kicad_pcb, HDMI.sch]
2020-09-08 Renaming - routing new GPDI PMOD
    [1-click-bom.csv, GPDI_ULX3S_PMOD.kicad_pcb, GPDI_ULX3S_PMOD.sch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]
2020-09-09 Adding panel template and panel
    [GPDI_ULX3S_PMOD_panel_template.kicad_pcb]
2020-09-15 Changing resistors needed to 3.3V
    [midi.kicad_pcb]
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2020-09-15 Changing GPDI connector as used on ULX3S
    [GPDI_ULX3S_PMOD.kicad_pcb, GPDI_ULX3S_PMOD.sch]
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2020-10-27 Adding GPDI version 1.5
    [GPDI_ULX3S_PMOD.kicad_pcb, GPDI_ULX3S_PMOD.sch]
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2021-02-04 Rerouting PCB - Adding logos
    [midi.kicad_pcb, midi.sch]
2023-08-23 GPDI update to KiCad 7, update PCA9306 package, Version to v1.6
    [GPDI_ULX3S-B_Cu.gbr, GPDI_ULX3S-B_Mask.gbr, GPDI_ULX3S-B_Paste.gbr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]
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2023-08-24 Adding panel and scripts for GPDI-ULX3S
    [GPDI_ULX3S_panel-B_Cu.gbr, GPDI_ULX3S_panel-B_Mask.gbr, GPDI_ULX3S_panel-B_Paste.gbr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]
2023-08-24 Upading USB extension to v1.1
    [USB-B_Cu.gbl, USB-B_Mask.gbs, USB-B_Paste.gbp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]

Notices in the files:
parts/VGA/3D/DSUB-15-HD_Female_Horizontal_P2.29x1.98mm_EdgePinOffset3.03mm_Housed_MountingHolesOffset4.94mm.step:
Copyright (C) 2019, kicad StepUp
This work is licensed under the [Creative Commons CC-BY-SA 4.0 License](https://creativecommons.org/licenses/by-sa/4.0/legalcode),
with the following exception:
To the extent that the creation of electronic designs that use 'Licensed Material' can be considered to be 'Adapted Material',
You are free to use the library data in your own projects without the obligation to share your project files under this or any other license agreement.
